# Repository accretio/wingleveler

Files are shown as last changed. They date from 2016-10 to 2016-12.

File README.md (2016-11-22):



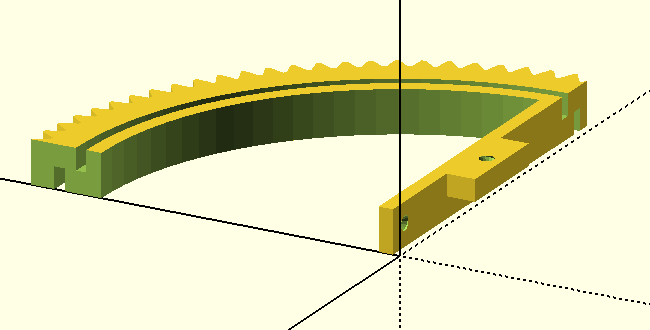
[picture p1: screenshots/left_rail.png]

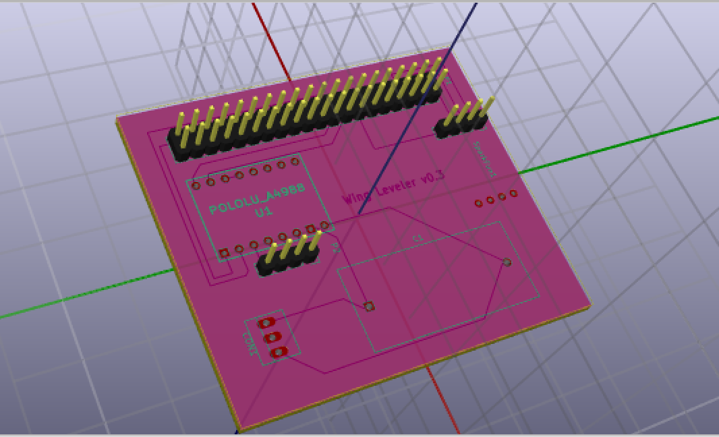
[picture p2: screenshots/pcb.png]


# Wing leveler

A portable wing leveler that attaches to the aircraft's yoke.

# Features

+ Portable, clamp-on device with a single point of attach
+ 12V, powered from the cigarette lighter socket
+ "Quick disconnect" button
+ "Follow present heading" button
+ Aural alarm if the aircraft departs more that 5 degrees from
assigned heading

# Technical highlights

+ 3d printed case
+ Raspberry Pi 3
+ InvenSense MPU-9250
+ NEMA 17 stepper motor
+ A4988 stepper driver

# Litterature

+ https://ocw.mit.edu/courses/aeronautics-and-astronautics/16-333-aircraft-stability-and-control-fall-2004/lecture-notes/

# Videos

+ https://www.youtube.com/watch?v=mazS7KZnoZ4
+ https://www.youtube.com/watch?v=BYXDKPSYu64

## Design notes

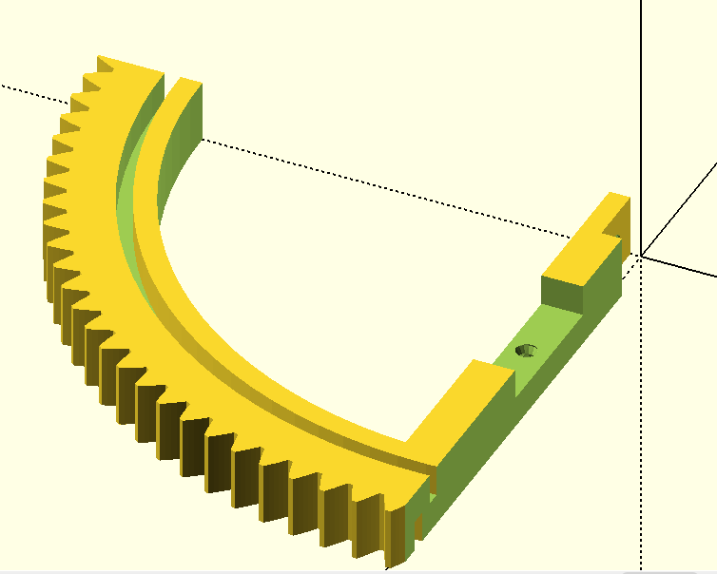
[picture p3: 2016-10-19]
screenshots/right_rail.png

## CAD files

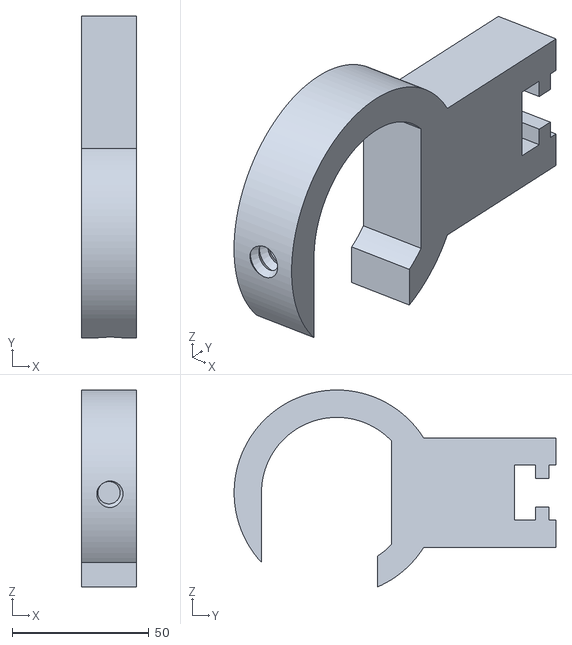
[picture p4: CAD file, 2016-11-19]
case/stl/left_clamp.stl
20.0 x 117.5 x 71.9

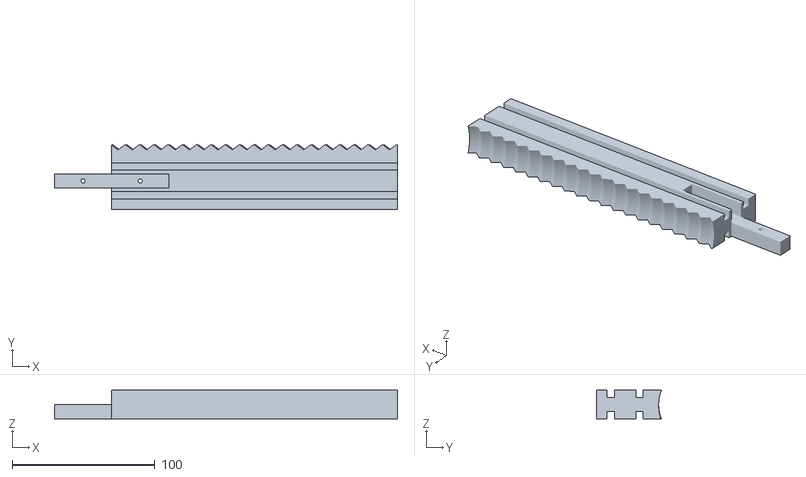
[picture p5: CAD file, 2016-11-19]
case/stl/left_common_rail.stl
240.0 x 45.5 x 20.0

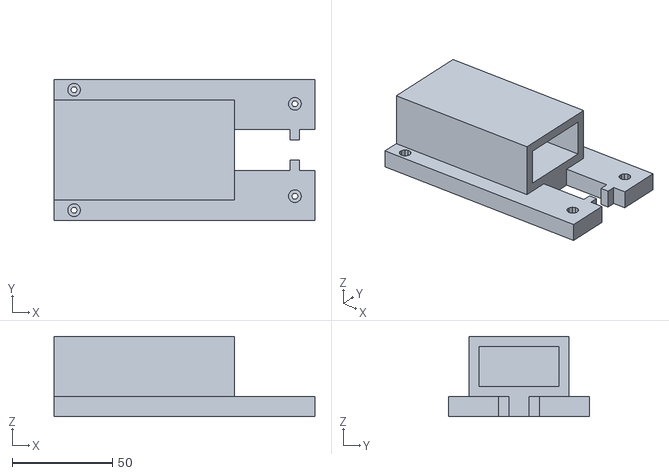
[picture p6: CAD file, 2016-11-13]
case/stl/flat_rail_left.stl
130.0 x 70.0 x 40.0

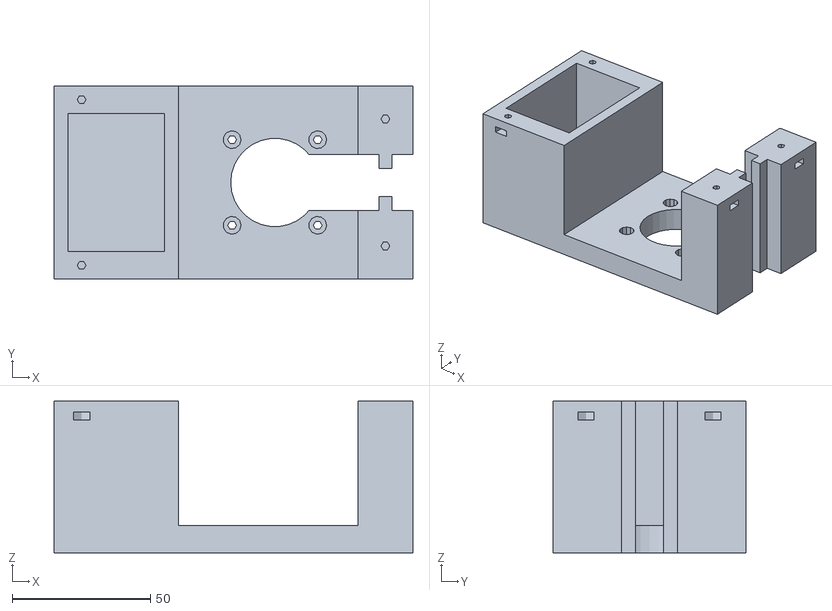
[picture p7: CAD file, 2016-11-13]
case/stl/flat_rail_large.stl
130.0 x 70.0 x 55.0

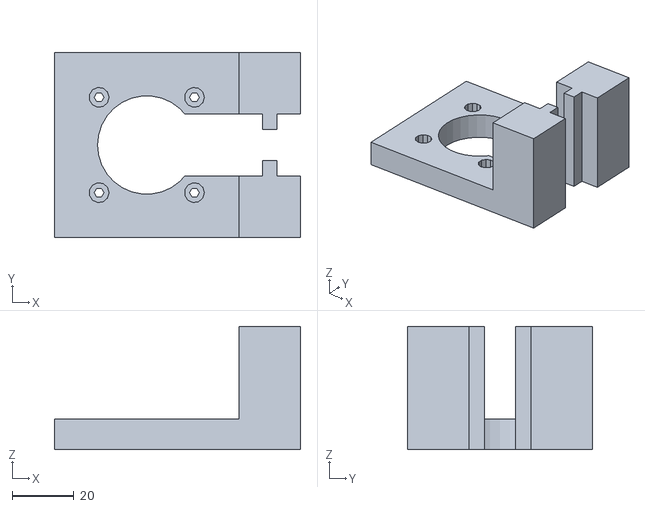
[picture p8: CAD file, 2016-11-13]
case/stl/plate2.stl
80.0 x 60.0 x 40.0

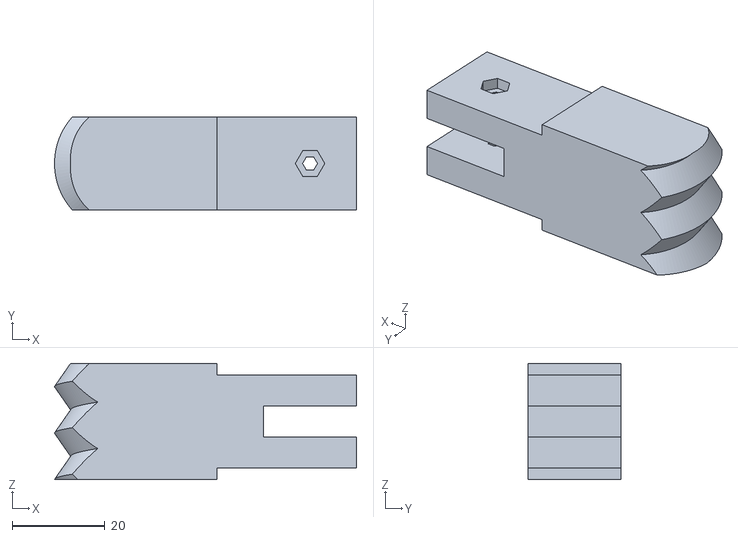
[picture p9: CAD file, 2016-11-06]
case/stl/flat_rail_1.stl
65.0 x 20.0 x 25.0

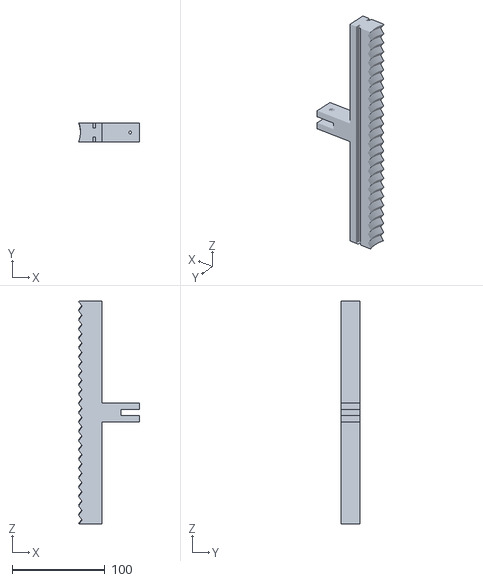
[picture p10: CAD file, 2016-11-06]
case/stl/flat_rail_2.stl
65.4 x 20.0 x 240.0

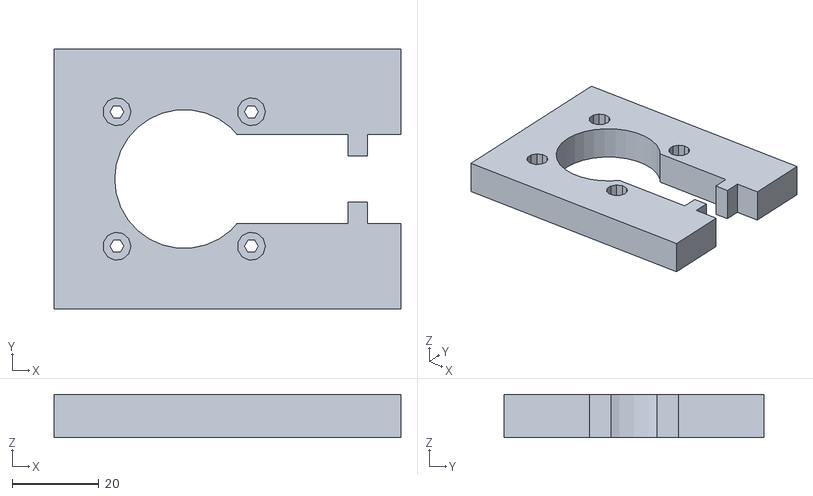
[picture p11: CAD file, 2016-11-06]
case/stl/flat_plate.stl
80.0 x 60.0 x 10.0

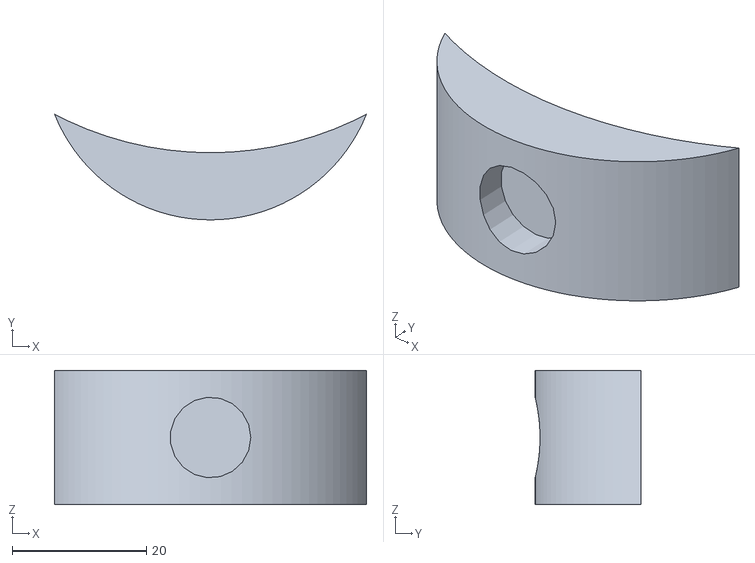
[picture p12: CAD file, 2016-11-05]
case/stl/pusher.stl
46.4 x 15.7 x 20.0

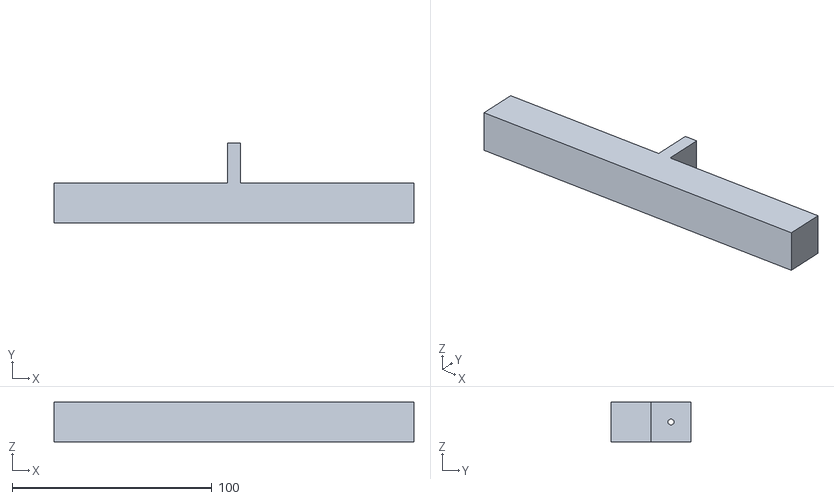
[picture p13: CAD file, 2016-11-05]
case/stl/clamp.stl
180.0 x 40.0 x 20.0

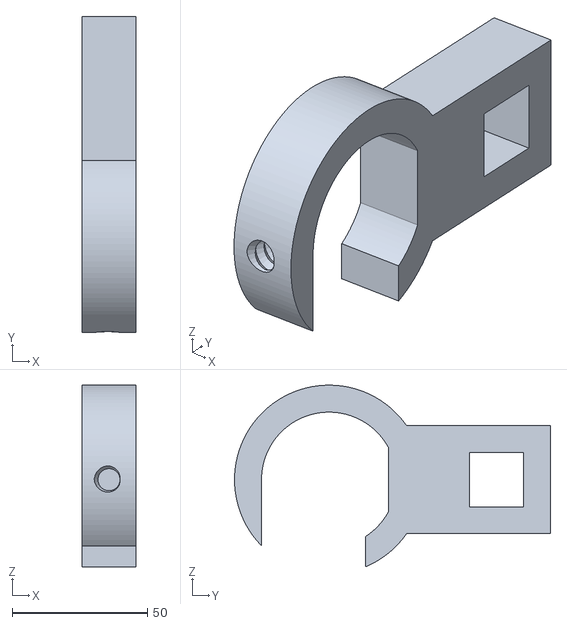
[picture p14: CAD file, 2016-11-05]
case/stl/holder.stl
20.0 x 117.0 x 67.3

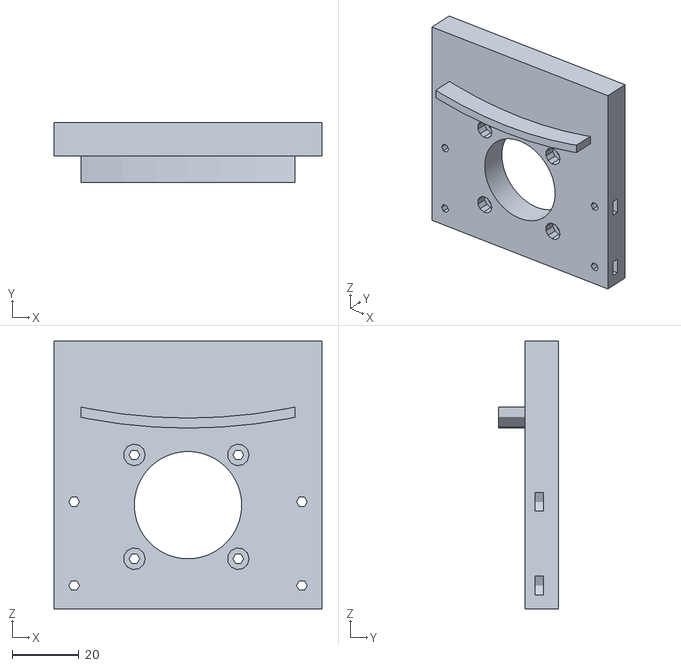
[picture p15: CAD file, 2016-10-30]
case/stl/front_controller.stl
80.0 x 18.0 x 80.0

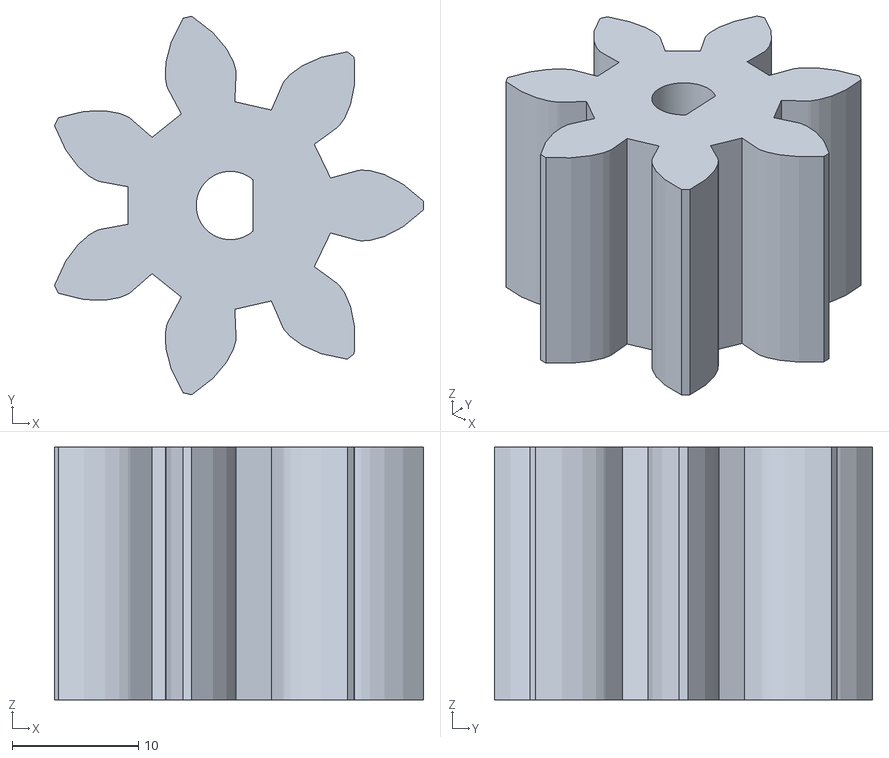
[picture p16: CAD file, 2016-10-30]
case/stl/driver_gear.stl
29.2 x 29.9 x 20.0

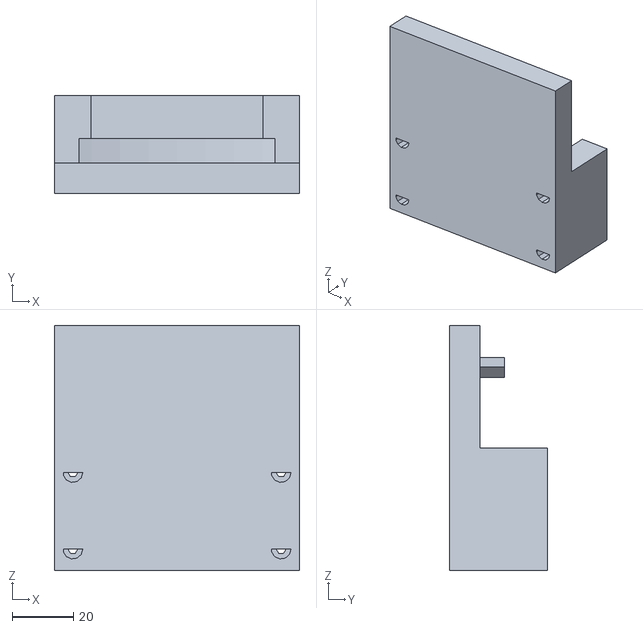
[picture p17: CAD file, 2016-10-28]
case/stl/back_controller.stl
80.0 x 32.0 x 80.0

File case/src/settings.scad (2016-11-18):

//// Parametrics settings

RingNumberOfTeeth=100;
DriverNumberOfTeeth=6;

ClampThickness=20;


// this is the diameter of the hole inside the clamp
ClampDiameter=55; 


ClampLength=30;
ClampZone=20;

GrooveWidth=5;

fn=100;


RingThickness = 20; 
RingDiameter=140;

Tolerance=0.1;

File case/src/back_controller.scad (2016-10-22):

use <controller.scad>

controller_back_plate();

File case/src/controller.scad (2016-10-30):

include <../deps/nutsnbolts/cyl_head_bolt.scad>

include <settings.scad> 
use <nema17.scad>
use <rail.scad>
use <raspberry_pi_3.scad>


// the controller is moving on the rail 

BoxWidth= 80;
BoxHeight=80;
Padding=4;  // unused

BoxDepth=10;



module controller_back_plate() {
  
    
     
   intersection(){
    translate([0, Tolerance, RingDiameter + 75]) {
        rotate([90, 0, 0]) {
            groove(RingDiameter+22 - Tolerance/2, GrooveWidth-Tolerance);
        }
    }

    translate([-BoxWidth/2 + BoxThickness,  -BoxDepth - Tolerance, BoxThickness]) {
            cube([BoxWidth - 2*BoxThickness , RingThickness + Tolerance, BoxHeight - BoxThickness], center=false);
        }

}
    difference(){ 
        translate([0, BoxDepth/2, BoxHeight/2]) {
            cube([BoxWidth, BoxDepth, BoxHeight], center=true);
        }
        translate([0, 20, 31]) {
            rotate([90, 0, 00]) {
                cylinder(RingThickness*2, 16, 16, $fn = fn); 
            }
        }
        nema_screws();
        block_screws();
    } 
}

Tolerance = 2;
BoxThickness = 8; 

module controller_front_plate() {
    
   
   intersection(){
    translate([0, -(BoxDepth + 2*Tolerance), RingDiameter + 75]) {
        rotate([90, 0, 0]) {
            groove(RingDiameter+12, GrooveWidth-Tolerance);
        }
    }
     translate([-BoxWidth/2 + BoxThickness, - RingThickness - Tolerance, BoxThickness]) {
            cube([BoxWidth - 2*BoxThickness , RingThickness + Tolerance, BoxHeight - BoxThickness], center=false);
        }
}
    difference() {
        translate([-BoxWidth/2, - RingThickness - BoxDepth - Tolerance, 0]) {
            cube([BoxWidth, BoxDepth + RingThickness + Tolerance, BoxHeight], center=false);
        }
         translate([-BoxWidth/2 + 1.5*BoxThickness, - RingThickness - Tolerance, 1.5*BoxThickness]) {
            cube([BoxWidth - 3*BoxThickness , RingThickness + Tolerance, BoxHeight - BoxThickness], center=false);
        }
        translate([-BoxWidth/2 , - RingThickness - Tolerance, BoxHeight / 2 ]) {
            cube([BoxWidth, RingThickness + Tolerance, BoxHeight / 2 ], center=false);
        }
        block_screws();
    } 
     
     
}


module m3_screw_for_nema() {
     rotate([90, 0, 0]) {
       // screw("M3x10", thread="modeled"); // screw M20x100 with thread
        translate([0, 0, 10]) hole_through(name="M3", l=10, cl=0.1, h=10, hcl=0.4);
    }
}

module nema_screws() {
    translate([15, 4, 15]) {
       m3_screw_for_nema();
    } 
    
    translate([-16, 4, 15]) {
        m3_screw_for_nema();
    }
    
    translate([-16, 4, 46]) {
       m3_screw_for_nema(); 
    }
    
    translate([15, 4, 46]) {
       m3_screw_for_nema();
    } 
}

module controller() { 
   
    
   controller_back_plate(); 
   //controller_front_plate(); 
  
}



module block_screw1() {
    rotate([90, 0, 0]) {
            //screw("M3x30", thread="modeled");
            translate([0, 0, 10]) hole_through(name="M3", l=35, cl=0.1, h=10, hcl=0.4);
            translate([0, 0, -25]) nutcatch_sidecut("M3", l=100, clk=0.1, clh=0.1, clsl=0.1);
        }
}

module block_screw2() {
    rotate([90, 0, 0]) {
            //screw("M3x30", thread="modeled");
            translate([0, 0, 10]) hole_through(name="M3", l=35, cl=0.1, h=10, hcl=0.4);
            rotate([0, 0, 180]) translate([0, 0, -25]) nutcatch_sidecut("M3", l=100, clk=0.1, clh=0.1, clsl=0.1);
        }
}

module block_screws() {
    translate([BoxWidth/2 - 0.75*BoxThickness, -RingThickness -Tolerance - BoxDepth + 10, 7]) {
       block_screw1(); 
    }
    
     translate([BoxWidth/2 - 0.75*BoxThickness, -RingThickness -Tolerance - BoxDepth + 10, 32]) {
         block_screw1(); 
    }
    
    translate([-BoxWidth/2 + 0.75*BoxThickness, -RingThickness -Tolerance - BoxDepth + 10, 32]) {
        block_screw2(); 
    }
    
     translate([-BoxWidth/2 + 0.75*BoxThickness, -RingThickness -Tolerance - BoxDepth + 10, 7]) {
        block_screw2(); 
    }
    
    
}


module pi_holder() {
     top();
}

module stepper_assembly() {
    translate([0, 0, -10]) {
            nema17();
    }
   /* gear (circular_pitch=p,
              gear_thickness = RingThickness,
		      rim_thickness = RingThickness,
		      hub_thickness = RingThickness,
		      circles=0,
		      number_of_teeth = DriverNumberOfTeeth,
		      rim_width = 0);  
    */
}

controller();
//stepper_assembly();

//controller();

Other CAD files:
case/stl/right_common_rail.stl
case/stl/right_rail.stl
case/stl/left_rail.stl
case/stl/rail.stl
case/src/driver_gear.scad
case/src/clamp.scad
case/src/flat_rail.scad
case/src/front_controller.scad
case/src/holder.scad
case/src/larger_system.scad
case/src/left_rail.scad
case/src/mount.scad
case/src/nema17.scad
case/src/parametric_involute_gear_v5.0.scad
case/src/polyScrewThread_r1.scad
case/src/polytests.scad
case/src/pusher.scad
case/src/rail.scad
case/src/raspberry_pi_3.scad
case/src/right_rail.scad
case/src/screw.scad
case/src/spur_generator.scad
case/src/utils.scad
case/stl/mount.stl
case/stl/screw.stl
case/stl/screw2.stl

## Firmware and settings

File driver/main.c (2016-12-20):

#include <stdio.h>
#include <time.h>
#include <math.h>
#include <pigpio.h>
#include <pthread.h>
#include <unistd.h>

#include "utils.h"
#include "inv_mpu.h"
#include "inv_mpu_dmp_motion_driver.h"
#include "quaternion.h"
#include "linux_glue.h"
#include "config.h"
#include "utils.h"
#include "state.h"
#include "control.h"
#include "manual.h"
#include "setup.h"
#include "ahrs.h"

int calibrate(struct state_t *state) {
  printf("hit any key when the weight reaches the end of the rail\n");
      
  while(!kbhit()) {
    step(state);
  }
  state->max_step = state->current_step;
  printf("max step is %d\n", state->max_step); 
  return;
}


int main(int argc, char **argv)
{

  int opt;
  struct state_t state ; 
  
  if (setup(&state)) {
    printf("couldn't set up properly, exiting\n");
    goto finalize; 
  }
  
  while ((opt = getopt(argc, argv, "culrp:a:m:k:")) != -1) {
    switch (opt) {
    case 'p':
      start_ahrs(&state);
      start_logging_directly(&state, optarg);
      break;
    case 'c':
      calibrate(&state);
      break;
    case 'u':
      center(&state);
      break;
    case 'l':
      set_direction(&state, NEMA_DIRECTION_LEFT);
      while(!kbhit()) {
        step(&state);
      }
      printf("final position is %d\n", state.current_step);
      break;
    case 'r':
      set_direction(&state, NEMA_DIRECTION_RIGHT);
      while(!kbhit()) {
        step(&state);
      }
      printf("final position is %d\n", state.current_step);
      break;
    case 'm':
      center(&state);
      start_logging(&state, optarg);
      start_ahrs(&state); 
      manual_loop(&state);
      goto finalize;
    case 'a':
      center(&state);
      printf("wing leveler is ready (max_step: %d) !\n", state.max_step);
      start_logging(&state, optarg);
      automated_loop(&state);
      goto finalize;
    case 'k':
      printf("wing leveler is ready(centered) (max_step: %d) !\n", state.max_step);
      state.current_step = MAX_STEP/2 ;
      start_logging(&state, optarg);
      automated_loop(&state);
      goto finalize;
    default:
      break;
    }
  }
        
 
  
 finalize:

  cleanup_state(&state);
         
  return 0;
      
}

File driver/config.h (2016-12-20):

#ifndef WINGLEVELER_CONFIG_H
#define WINGLEVELER_CONFIG_H

// GPIO Configuration

#define GPIO_NEMA_DIRECTION_PIN 24
#define GPIO_NEMA_STEP_PIN 23

#define GPIO_LIMIT_SWITCH_LEFT 4
#define GPIO_LIMIT_SWITCH_RIGHT 18

// NEMA BEHAVIOR

#define NEMA_DIRECTION_LEFT 0
#define NEMA_DIRECTION_RIGHT 1
#define NEMA_17_STEP_PAUSE 2000
#define NEMA_17_STEP_PAUSE_INCREMENT 100

// IMU 9250

#define IMU_IC2_BUS 1

// Some helpers

#define VEC_X 0
#define VEC_Y 1

// Math 101

#define	RAD_TO_DEGREE (180.0f / (float)M_PI)

// Wing leveler configuration

// TODO use limit switches instead of hardcoded limits
#define MAX_STEP 6655

#define DRIFT_THRESHOLD 1
#define DRIFT_MAX 30

#define MONITORING_DELAY 200
#define MAGNIFICATION_FACTOR 10

#define SAMPLE_RATE 10

// Correction logic

#define BANK_TOLERANCE 1
#define BANK_CORRECTION_FACTOR 1

#define WARMING_DELAY 5000

#endif

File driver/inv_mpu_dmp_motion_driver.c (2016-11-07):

/*
 $License:
    Copyright (C) 2011-2012 InvenSense Corporation, All Rights Reserved.
    See included License.txt for License information.
 $
 */
/**
 *  @addtogroup  DRIVERS Sensor Driver Layer
 *  @brief       Hardware drivers to communicate with sensors via I2C.
 *
 *  @{
 *      @file       inv_mpu_dmp_motion_driver.c
 *      @brief      DMP image and interface functions.
 *      @details    All functions are preceded by the dmp_ prefix to
 *                  differentiate among MPL and general driver function calls.
 */
#include <stdio.h>
#include <stdint.h>
#include <stdlib.h>
#include <string.h>
#include <math.h>
#include "inv_mpu.h"
#include "inv_mpu_dmp_motion_driver.h"
#include "dmpKey.h"
#include "dmpmap.h"

/* The following functions must be defined for this platform:
 * i2c_write(unsigned char slave_addr, unsigned char reg_addr,
 *      unsigned char length, unsigned char const *data)
 * i2c_read(unsigned char slave_addr, unsigned char reg_addr,
 *      unsigned char length, unsigned char *data)
 * delay_ms(unsigned long num_ms)
 * get_ms(unsigned long *count)
 */


#if defined RASPBERRY_PI

#include "linux_glue.h"

#elif defined EMPL_TARGET_STM32F4
#include "i2c.h"   
#include "main.h"
#include "board-st_discovery.h"
   
#define i2c_write   Sensors_I2C_WriteRegister
#define i2c_read    Sensors_I2C_ReadRegister
#define get_ms      get_tick_count

#elif defined MOTION_DRIVER_TARGET_MSP430
#include "msp430.h"
#include "msp430_clock.h"
#define delay_ms    msp430_delay_ms
#define get_ms      msp430_get_clock_ms
#define log_i(...)     do {} while (0)
#define log_e(...)     do {} while (0)

#elif defined EMPL_TARGET_MSP430
#include "msp430.h"
#include "msp430_clock.h"
#include "log.h"
#define delay_ms    msp430_delay_ms
#define get_ms      msp430_get_clock_ms
#define log_i       MPL_LOGI
#define log_e       MPL_LOGE

#elif defined EMPL_TARGET_UC3L0
/* Instead of using the standard TWI driver from the ASF library, we're using
 * a TWI driver that follows the slave address + register address convention.
 */
#include "delay.h"
#include "sysclk.h"
#include "log.h"
#include "uc3l0_clock.h"
/* delay_ms is a function already defined in ASF. */
#define get_ms  uc3l0_get_clock_ms
#define log_i       MPL_LOGI
#define log_e       MPL_LOGE

#else
#error  Gyro driver is missing the system layer implementations.
#endif

/* These defines are copied from dmpDefaultMPU6050.c in the general MPL
 * releases. These defines may change for each DMP image, so be sure to modify
 * these values when switching to a new image.
 */
#define CFG_LP_QUAT             (2712)
#define END_ORIENT_TEMP         (1866)
#define CFG_27                  (2742)
#define CFG_20                  (2224)
#define CFG_23                  (2745)
#define CFG_FIFO_ON_EVENT       (2690)
#define END_PREDICTION_UPDATE   (1761)
#define CGNOTICE_INTR           (2620)
#define X_GRT_Y_TMP             (1358)
#define CFG_DR_INT              (1029)
#define CFG_AUTH                (1035)
#define UPDATE_PROP_ROT         (1835)
#define END_COMPARE_Y_X_TMP2    (1455)
#define SKIP_X_GRT_Y_TMP        (1359)
#define SKIP_END_COMPARE        (1435)
#define FCFG_3                  (1088)
#define FCFG_2                  (1066)
#define FCFG_1                  (1062)
#define END_COMPARE_Y_X_TMP3    (1434)
#define FCFG_7                  (1073)
#define FCFG_6                  (1106)
#define FLAT_STATE_END          (1713)
#define SWING_END_4             (1616)
#define SWING_END_2             (1565)
#define SWING_END_3             (1587)
#define SWING_END_1             (1550)
#define CFG_8                   (2718)
#define CFG_15                  (2727)
#define CFG_16                  (2746)
#define CFG_EXT_GYRO_BIAS       (1189)
#define END_COMPARE_Y_X_TMP     (1407)
#define DO_NOT_UPDATE_PROP_ROT  (1839)
#define CFG_7                   (1205)
#define FLAT_STATE_END_TEMP     (1683)
#define END_COMPARE_Y_X         (1484)
#define SKIP_SWING_END_1        (1551)
#define SKIP_SWING_END_3        (1588)
#define SKIP_SWING_END_2        (1566)
#define TILTG75_START           (1672)
#define CFG_6                   (2753)
#define TILTL75_END             (1669)
#define END_ORIENT              (1884)
#define CFG_FLICK_IN            (2573)
#define TILTL75_START           (1643)
#define CFG_MOTION_BIAS         (1208)
#define X_GRT_Y                 (1408)
#define TEMPLABEL               (2324)
#define CFG_ANDROID_ORIENT_INT  (1853)
#define CFG_GYRO_RAW_DATA       (2722)
#define X_GRT_Y_TMP2            (1379)

#define D_0_22                  (22+512)
#define D_0_24                  (24+512)

#define D_0_36                  (36)
#define D_0_52                  (52)
#define D_0_96                  (96)
#define D_0_104                 (104)
#define D_0_108                 (108)
#define D_0_163                 (163)
#define D_0_188                 (188)
#define D_0_192                 (192)
#define D_0_224                 (224)
#define D_0_228                 (228)
#define D_0_232                 (232)
#define D_0_236                 (236)

#define D_1_2                   (256 + 2)
#define D_1_4                   (256 + 4)
#define D_1_8                   (256 + 8)
#define D_1_10                  (256 + 10)
#define D_1_24                  (256 + 24)
#define D_1_28                  (256 + 28)
#define D_1_36                  (256 + 36)
#define D_1_40                  (256 + 40)
#define D_1_44                  (256 + 44)
#define D_1_72                  (256 + 72)
#define D_1_74                  (256 + 74)
#define D_1_79                  (256 + 79)
#define D_1_88                  (256 + 88)
#define D_1_90                  (256 + 90)
#define D_1_92                  (256 + 92)
#define D_1_96                  (256 + 96)
#define D_1_98                  (256 + 98)
#define D_1_106                 (256 + 106)
#define D_1_108                 (256 + 108)
#define D_1_112                 (256 + 112)
#define D_1_128                 (256 + 144)
#define D_1_152                 (256 + 12)
#define D_1_160                 (256 + 160)
#define D_1_176                 (256 + 176)
#define D_1_178                 (256 + 178)
#define D_1_218                 (256 + 218)
#define D_1_232                 (256 + 232)
#define D_1_236                 (256 + 236)
#define D_1_240                 (256 + 240)
#define D_1_244                 (256 + 244)
#define D_1_250                 (256 + 250)
#define D_1_252                 (256 + 252)
#define D_2_12                  (512 + 12)
#define D_2_96                  (512 + 96)
#define D_2_108                 (512 + 108)
#define D_2_208                 (512 + 208)
#define D_2_224                 (512 + 224)
#define D_2_236                 (512 + 236)
#define D_2_244                 (512 + 244)
#define D_2_248                 (512 + 248)
#define D_2_252                 (512 + 252)
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

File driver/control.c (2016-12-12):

#include <stdio.h>
#include <pigpio.h>
#include "config.h"
#include "state.h"

int set_direction(struct state_t *state, int direction) {
  if (state->current_direction != direction) {
    if (gpioWrite(GPIO_NEMA_DIRECTION_PIN, direction)) {
      printf("couldn't set up the direction\n");
      return -1;
    }
    state->current_direction = direction;
  }
  return 0;
}

int step(struct state_t *state)
{

  if (state->current_direction == NEMA_DIRECTION_RIGHT &&
      !gpioRead(GPIO_LIMIT_SWITCH_RIGHT)) {
    printf("going right, right switch on\n");
    return -1; 
  }
  
  if (state->current_direction == NEMA_DIRECTION_LEFT &&
      !gpioRead(GPIO_LIMIT_SWITCH_LEFT)) {
       printf("going left, left switch on\n");
       return -1; 
  }
    
  if (gpioWrite(GPIO_NEMA_STEP_PIN, 1)) {
    printf("couldn't write to the step pin\n");
    return -1;
  }

  if (gpioWrite(GPIO_NEMA_STEP_PIN, 0)) {
    printf("couldn't write to the step pin\n");
    return -1;
  }
  
  if (state->current_direction == NEMA_DIRECTION_RIGHT) { 
    state->current_step = state->current_step + 1 ;
  } else {
    state->current_step = state->current_step - 1 ;
  }
  
  gpioSleep(PI_TIME_RELATIVE, 0, state->nema_pause);
  return 0; 
}

int center(struct state_t *state)
{
  set_direction(state, NEMA_DIRECTION_LEFT);
  // go all the way to the left
  while(!step(state)) {
   
  };
  // reset the current position
  printf("left stop found\n");
  state->current_step = 0;
  // go all the way to the right
  set_direction(state, NEMA_DIRECTION_RIGHT);
  while(!step(state)) {};
  state->max_step = state->current_step;
  printf("right stop found at %d\n", state->max_step);
  // back in the middle
  set_direction(state, NEMA_DIRECTION_LEFT);
  while(state->current_step > state->max_step / 2) {
    step(state);
  }
  printf("centered\n");
  return 0;
}

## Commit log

2016-10-06 first commit - drafts
    [clamp.scad, mount.scad, parametric_involute_gear_v5.0.scad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]
2016-10-09 working on the mount
    [mount.scad]
2016-10-09 working on the clamp
    [clamp.scad, mount.scad]
2016-10-09 clamp with screws
    [clamp.scad]
2016-10-19 little commit before resuming working
    [clamp.scad, screw.scad]
2016-10-19 left & right rails, clamp
    [clamp.scad, mount.scad, rail.scad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]
2016-10-19 adding the groove
    [rail.scad, settings.scad]
2016-10-19 moving code around
    [clamp.scad, rail.scad, settings.scad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]
2016-10-19 adding individual files for the 3 elements
    [left_rail.scad, rail.scad, right_rail.scad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]
2016-10-19 adding the stls
    [clamp.stl, left_rail.stl, mount.stl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]
2016-10-19 cleaning up
    [clamp.scad, clamp.stl, left_rail.scad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]
2016-10-22 wip central holder
    [back_controller.scad, controller.scad, nema17.scad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]
2016-10-22 adding back & front controller boxes
    [controller.scad, front_controller.scad]
2016-10-22 more renderings
    [back_controller.stl, clamp.scad, controller.scad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]
2016-10-24 moving the clamp screw to give a chance to the lip to form
    [clamp.scad, left_rail.stl, rail.scad]
2016-10-25 adding small lip on driver gear
    [driver_gear.scad]
2016-10-25 moving lip
    [driver_gear.scad]
2016-10-25 adding stl
    [driver_gear.stl]
2016-10-28 little modifications
    [back_controller.scad, clamp.scad, controller.scad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]
2016-10-28 new groove
    [back_controller.stl, controller.scad, front_controller.stl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]
2016-10-30 various case tuning
    [clamp.scad, clamp.stl, controller.scad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]
2016-10-30 moving files around
    [back_controller.scad, back_controller.stl, clamp.scad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]
2016-10-30 initializing the driver
2016-10-30 playing with the mpu driver
2016-10-30 playing with i2c
2016-10-30 crappy calibration
2016-10-30 refactoring the driver code
2016-11-02 adding a little pusher
    [clamp.scad, pusher.scad, pusher.stl]
2016-11-05 some modifications to accomodate the measurements of the yokes
    [clamp.scad, clamp.stl, holder.scad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]
2016-11-05 working on the threaded rod
    [flat_rail.scad]
2016-11-06 more work on the case
    [flat_plate.stl, flat_rail.scad, flat_rail_1.stl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]
2016-11-07 little changes to the driver
    [flat_rail.scad]
2016-11-07 using the accelerometer
2016-11-12 flat rail
    [flat_rail.scad]
2016-11-13 bigger, hollow moving part
    [flat_rail.scad, flat_rail_large.stl, plate2.stl]
2016-11-13 adding a left side to hold the weights
    [flat_rail.scad, flat_rail_left.stl]
2016-11-13 saving 5mm
    [flat_rail.scad]
2016-11-17 handling movements from a separate thread
2016-11-18 extending the arm
    [clamp.scad, flat_rail.scad, larger_system.scad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]
2016-11-18 adding the rod
    [larger_system.scad]
2016-11-19 stls for v0.3
    [larger_system.scad, left_clamp.stl, left_common_rail.stl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]
2016-11-22 initial shot at doing a pcb
    [pcb.kicad_pcb, pcb.sch]
2016-11-22 fitting all the components on the pi top
    [pcb.kicad_pcb, pcb.sch]
2016-11-22 adding pcb screenshot
2016-12-06 works better if you actually start the servo
2016-12-11 adding setup & config for the limit switch
